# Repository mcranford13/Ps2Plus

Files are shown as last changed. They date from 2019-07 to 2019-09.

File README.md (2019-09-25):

# **PS2 Plus**

This project is a work in progress for making a PS2 Controller emulator. It was designed for the **PIC16F18876** microcontroller. As of right now the controller emulation is working great. There are still some features that I want to add but the main part of the project is complete. 

There are several hold-ups keeping this project from being complete, the main one being that writing an application for the PS2 and being able to send custom commands to the controller is difficult. I am slowly deciphering everything done by the PS2Dev team but it is slow going. If anyone would like to contribute or offer help/advice, I would gladly take it.

This project consists of several smaller projects each with its own folder, and is, as follows:

**firmware** - Main code of the project. Contains the PS2 protocol code.

**hardware** - The schematics and pcb design of the project. Includes information regarding external circuitry.

**updater** - The PS2 application for updating the controller.

**bootloader** - The bootloader code for the mcu.

**docs** - Contains datasheets, pinouts, and other useful documentation.

## **TODO**

- Bootloader
- PS2 Updater Application

## **Build**

You will need a pickit3, MPLAB (_free_), and XC8 compiler to flash this. To build from source, open the firmware project in MPLAB and click 'run'. This will compile the project and then initiate the transfer to the mcu.

The correct pinout of the microcontroller can be found in the **docs** folder.

## **Analog Stick Setup**

> 1. Press Select, L1, and L2 to enter configuration mode. The PS2 should say that there is no controller connected (if you are in a game).
> 2. Move the analog sticks slowly in a circle.
> 3. Press Select, L1, and R1 to exit. The PS2 should now recognize the controller.
> 4. Reboot the controller (rebooting the ps2 works too).
> Analog sticks should now be working.

To set the analog sticks back to the default values:
> 1. Press Select, L1, and L2 to enter configuration mode.
> 2. Press L2, R2, Select, Start.
> 3. Reboot controller (or ps2).

## **Hardware**
Please note that this is my first pcb design and if there are mistakes or any room for improvement please make an issue or a pull request. I am always happy to learn and improve. 

I have recieved feedback that the pad layout of the pcb is not optimal, this occured due to the pins chosen during the prototyping phase and when I switched from the DIP to the TQFP. I intend to update this but I am been really busy with school and life. Therefore I will release it how it is for now, and update it when I get a chance. If anyone would like to submit an updated pcb, I'd be happy to include it. Thanks for your understanding.

## **Acknowledgements**

This project has only moved forward due to these individuals and sites (in no particular order):

1. [Curious Inventor](http://store.curiousinventor.com/guides/PS2) - documentation of the PS2 controller Protocol
2. [Scanlime](https://gist.github.com/scanlime/5042071) - documentation of the PS2 controller protocol
3. [Aurelio Manara](https://github.com/Aurelio92/GCPlus) - for answering countless questions and advice.
4. [Gman](https://gmanmodz.com/) - for initial interest in this project and countless contributions to it.
5. [PS2Dev Team](https://github.com/ps2dev) - for all the hard and amazing work on homebrew for the PS2.

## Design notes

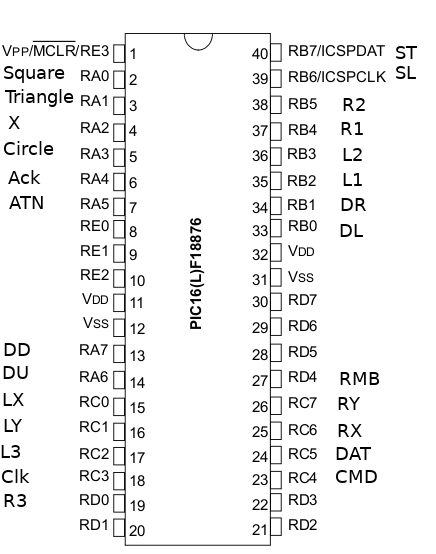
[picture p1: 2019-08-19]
doc/pinout.png

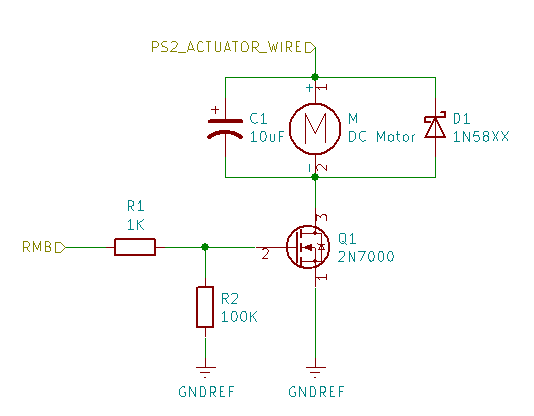
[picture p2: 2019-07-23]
hardware/rumbleSch.png

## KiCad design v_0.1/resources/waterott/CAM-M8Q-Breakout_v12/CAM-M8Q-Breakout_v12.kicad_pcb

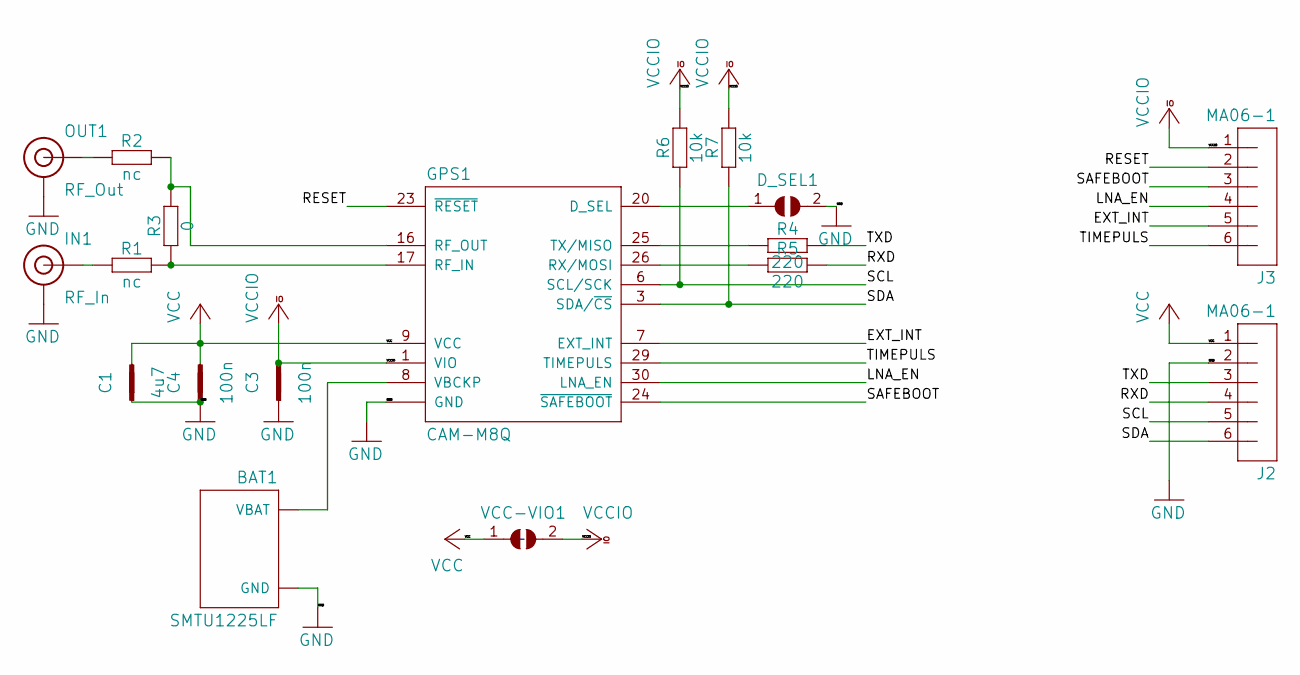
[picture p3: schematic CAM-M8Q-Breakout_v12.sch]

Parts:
BAT1: SMTU1225LF; BAT-SMTU1225LF
C1: 4u7; C0402
C3, C4: 100n; C0402
D_SEL1: JUMPER2-0603-NC; JUMPER2-0603_NC
GPS1: CAM-M8Q
IN1: RF_In; U.FL
J2, J3: MA06-1
OUT1: RF_Out; U.FL
R1, R2: nc; C0402
R3: 0; C0402
R4, R5: 220; C0402
R6, R7: 10k; C0402
VCC-VIO1: JUMPER2-0603-NC; JUMPER2-0603_NC

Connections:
/EXT_INT: GPS1.7 (EXT_INT), J3.5
/LNA_EN: GPS1.30 (LNA_EN), J3.4
/RESET: GPS1.23 (~RESET), J3.2
/RXD: J2.4, R5.2
/SAFEBOOT: GPS1.24 (~SAFEBOOT), J3.3
/SCL: GPS1.6 (SCL/SCK), J2.5, R6.1
/SDA: GPS1.3 (SDA/~CS), J2.6, R7.1
/TIMEPULS: GPS1.29 (TIMEPULS), J3.6
/TXD: J2.3, R4.2
GND: BAT1.- (GND), C1.1, C3.1, C4.1, D_SEL1.2, GPS1.4 (GND), GPS1.5 (GND), GPS1.10 (GND), GPS1.11 (GND), GPS1.12 (GND), GPS1.13 (GND), GPS1.14 (GND), GPS1.15 (GND), GPS1.18 (GND), GPS1.19 (GND), GPS1.21 (GND), GPS1.22 (GND), GPS1.27 (GND), GPS1.31 (GND), IN1.1 (GND), IN1.2 (GND), J2.2, OUT1.1 (GND), OUT1.2 (GND)
unnamed: BAT1.+ (VBAT), GPS1.8 (VBCKP)
unnamed: D_SEL1.1, GPS1.20 (D_SEL)
unnamed: GPS1.16 (RF_OUT), R2.2, R3.2
unnamed: GPS1.17 (RF_IN), R1.2, R3.1
unnamed: GPS1.25 (TX/MISO), R4.1
unnamed: GPS1.26 (RX/MOSI), R5.1
unnamed: IN1.FEED (SIGNAL), R1.1
unnamed: OUT1.FEED (SIGNAL), R2.1
VCC: C1.2, C4.2, GPS1.9 (VCC), J2.1, VCC-VIO1.1
VCCIO: C3.2, GPS1.1 (VIO), J3.1, R6.2, R7.2, VCC-VIO1.2

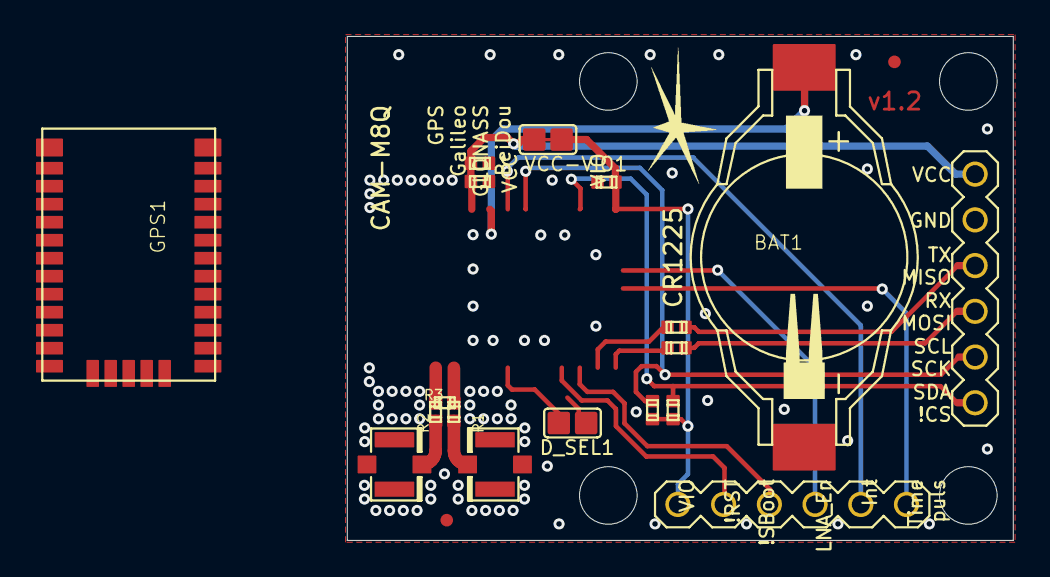
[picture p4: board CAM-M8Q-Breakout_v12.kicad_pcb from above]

Board: 2 copper layers, 37.0 x 28.0 mm, 31 parts (0 on the bottom side), 20 nets.

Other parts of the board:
@HOLE0, @HOLE1, @HOLE2, @HOLE3: (no value)
LOGO1: LOGO-S_PLACE_M; SPARK_TPLACE_M
LOGO2: OSHW_LOGOX0070; OSHW_6X70
LOGO3: LOGO_CE-2; CE_2MM
LOGO4: LOGO_WEEE-4; WEEE_4MM
LOGO5: LOGO_ROHS-2; ROHS_2MM
X1, X2, X3, X4: PASSER-07; PASSER_07MM

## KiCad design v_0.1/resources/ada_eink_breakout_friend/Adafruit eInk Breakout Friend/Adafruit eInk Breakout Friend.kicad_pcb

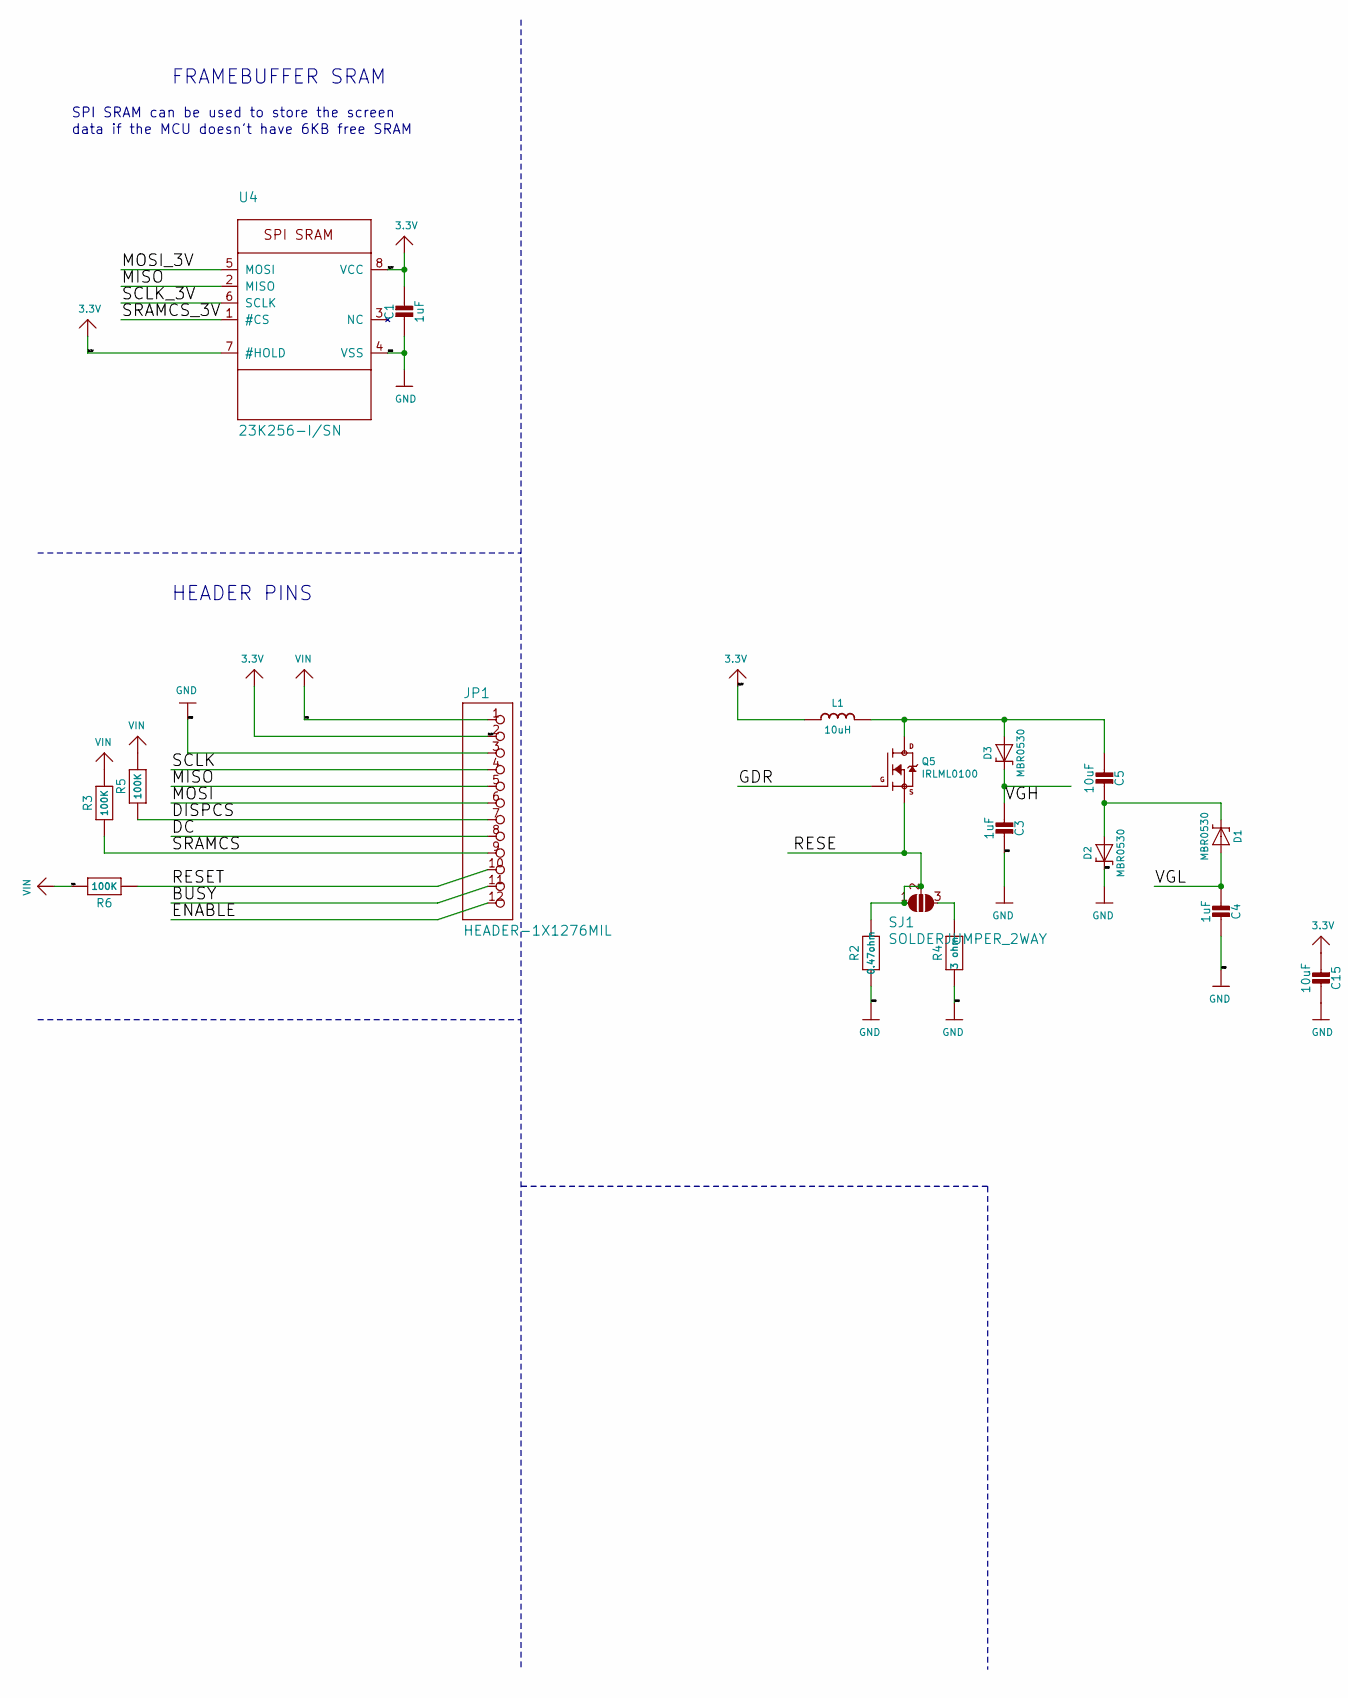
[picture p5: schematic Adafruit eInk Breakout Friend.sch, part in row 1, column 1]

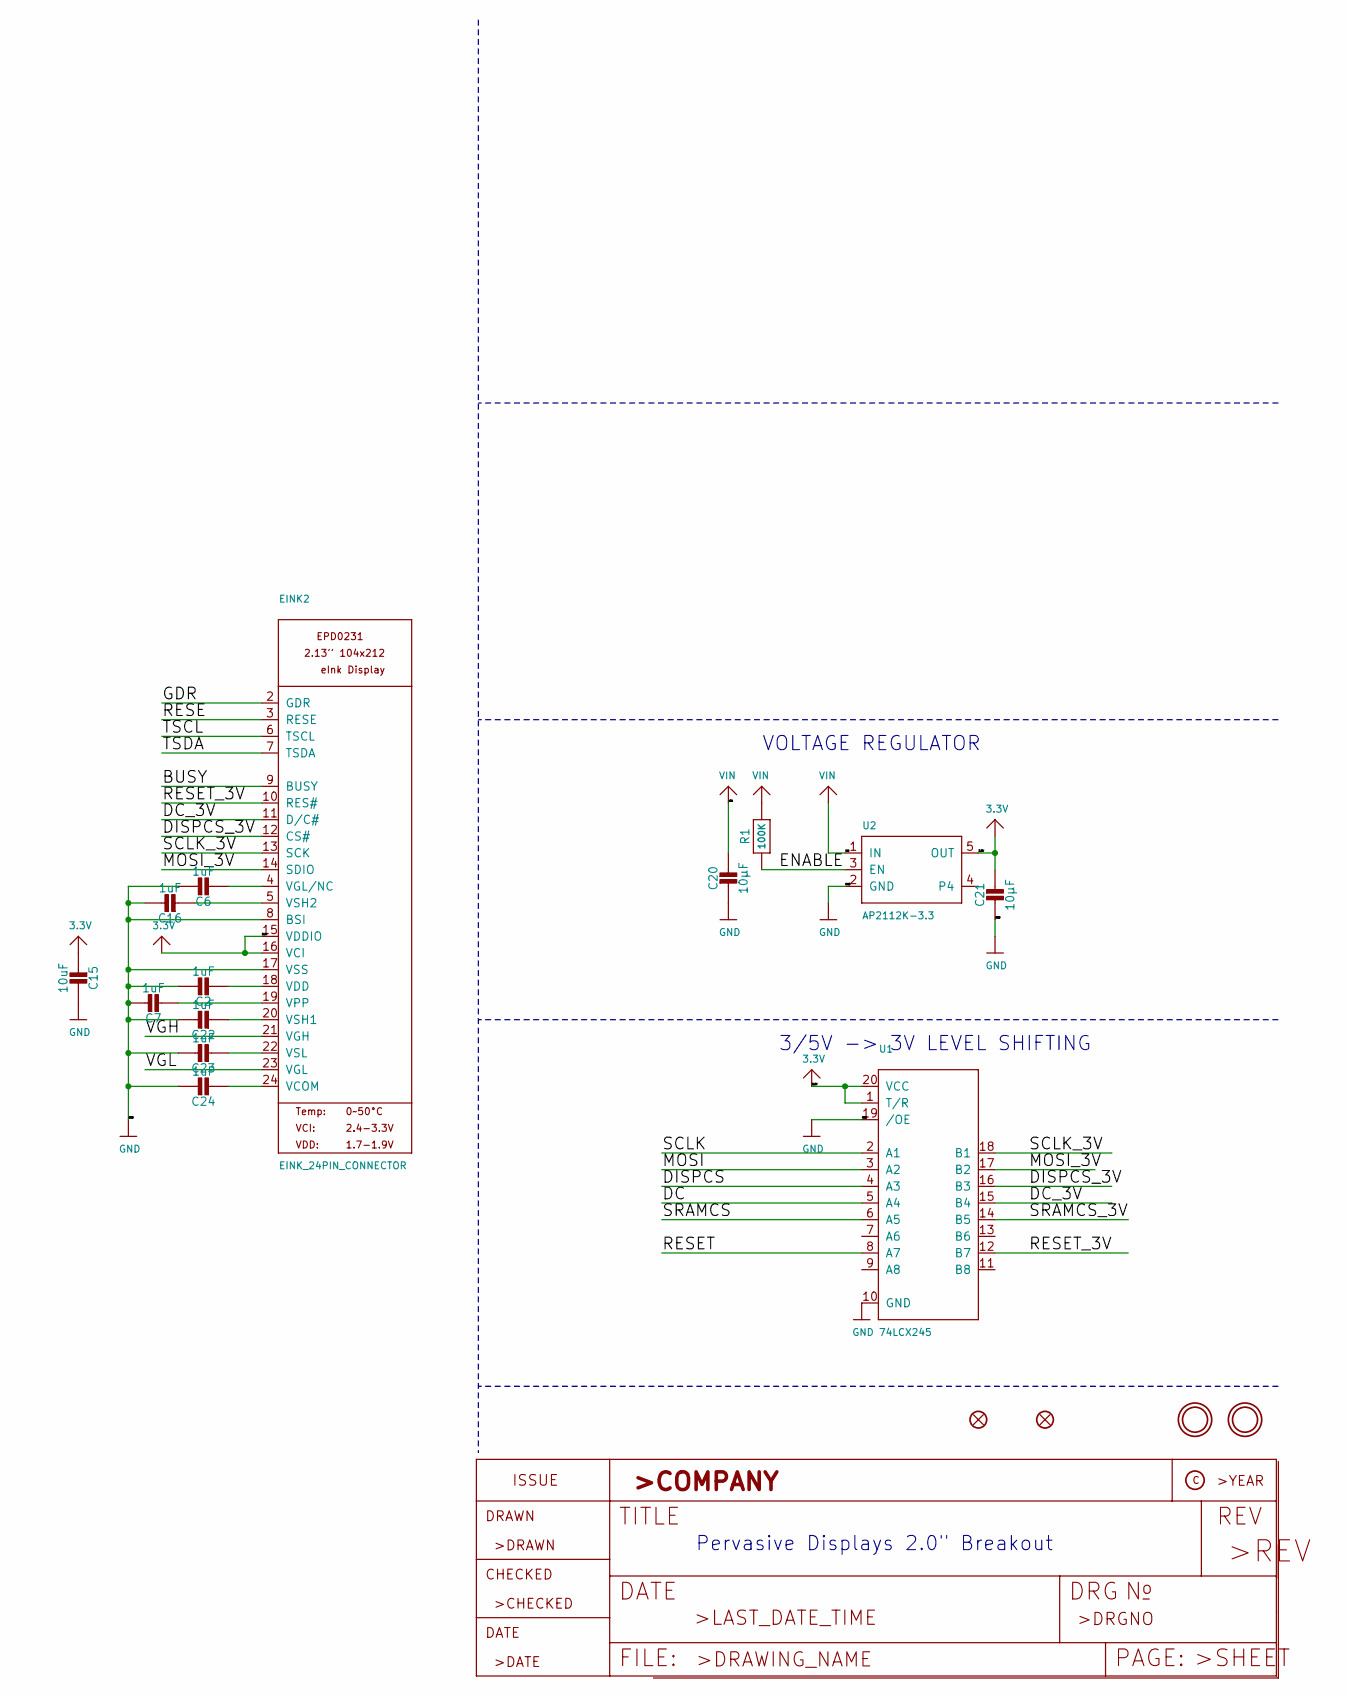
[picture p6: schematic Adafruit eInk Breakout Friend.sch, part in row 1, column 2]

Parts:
C1: 1uF; 0805_10MGAP
C2, C3, C4, C6, C7, C16, C22, C23, C24: 1uF; 0805-NO
C5, C15: 10uF; 0805-NO
C20, C21: 10µF; 0805-NO
D1, D2, D3: MBR0530; SOD-123
EINK2: EINK_24PIN_CONNECTOR; EINK_24PIN
FID2, FID3: FIDUCIAL_1MM
JP1: HEADER-1X1276MIL; 1X12_ROUND_76MIL
L1: 10uH; INDUCTOR_4X4MM_NR401
Q5: IRLML0100; SOT23-3
R1, R3, R5, R6: 100K; 0603-NO
R2: 0.47ohm; 0805-NO
R4: 3 ohm; 0805-NO
SJ1: SOLDERJUMPER_2WAY; SOLDERJUMPER_2WAY_OPEN_NOPASTE
U1: 74LCX245; TSSOP20
U2: AP2112K-3.3; SOT23-5
U4: 23K256-I/SN; SOIC8_150MIL
U$3, U$4: MOUNTINGHOLE2.5; MOUNTINGHOLE_2.5_PLATED

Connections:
3.3V: C1.1, C15.2, C21.1, EINK2.15 (VDDIO), EINK2.16 (VCI), JP1.2, L1.P$2 (2), U1.1 (T/R), U1.20 (VCC), U2.5 (OUT), U4.7 (#HOLD), U4.8 (VCC)
/BUSY: EINK2.9 (BUSY), JP1.11
/DC: JP1.8, U1.5 (A4)
/DC_3V: EINK2.11 (D/C#), U1.15 (B4)
/DISPCS: JP1.7, R5.1, U1.4 (A3)
/DISPCS_3V: EINK2.12 (CS#), U1.16 (B3)
/ENABLE: JP1.12, R1.1, U2.3 (EN)
/GDR: EINK2.2 (GDR), Q5.1 (G)
/MISO: JP1.5, U4.2 (MISO)
/MOSI: JP1.6, U1.3 (A2)
/MOSI_3V: EINK2.14 (SDIO), U1.17 (B2), U4.5 (MOSI)
/RESE: EINK2.3 (RESE), Q5.2 (S), R2.1, SJ1.1, SJ1.2
/RESET: JP1.10, R6.1, U1.8 (A7)
/RESET_3V: EINK2.10 (RES#), U1.12 (B7)
/SCLK: JP1.4, U1.2 (A1)
/SCLK_3V: EINK2.13 (SCK), U1.18 (B1), U4.6 (SCLK)
/SRAMCS: JP1.9, R3.1, U1.6 (A5)
/SRAMCS_3V: U1.14 (B5), U4.1 (#CS)
/TSCL: EINK2.6 (TSCL)
/TSDA: EINK2.7 (TSDA)
/VGH: C3.1, D3.C, EINK2.21 (VGH)
/VGL: C4.1, D1.A, EINK2.23 (VGL)
GND: C1.2, C2.1, C3.2, C4.2, C6.1, C7.1, C15.1, C16.1, C20.2, C21.2, C22.1, C23.1, C24.1, D2.C, EINK2.8 (BSI), EINK2.17 (VSS), JP1.3, R2.2, R4.2, U1.10 (GND), U1.19 (/OE), U2.2 (GND), U4.4 (VSS)
unnamed: C2.2, EINK2.18 (VDD)
unnamed: C5.1, D3.A, L1.P$1 (1), Q5.3 (D)
unnamed: C5.2, D1.C, D2.A
unnamed: C6.2, EINK2.4 (VGL/NC)
unnamed: C7.2, EINK2.19 (VPP)
unnamed: C16.2, EINK2.5 (VSH2)
unnamed: C22.2, EINK2.20 (VSH1)
unnamed: C23.2, EINK2.22 (VSL)
unnamed: C24.2, EINK2.24 (VCOM)
unnamed: R4.1, SJ1.3
VIN: C20.1, JP1.1, R1.2, R3.2, R5.2, R6.2, U2.1 (IN)

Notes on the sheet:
Pervasive Displays 2.0" Breakout
VOLTAGE REGULATOR
3/5V -> 3V LEVEL SHIFTING
HEADER PINS
FRAMEBUFFER SRAM
SPI SRAM can be used to store the screen
data if the MCU doesn't have 6KB free SRAM

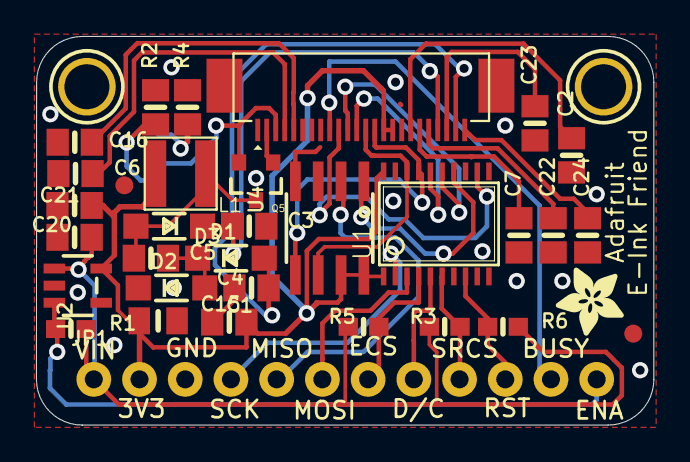
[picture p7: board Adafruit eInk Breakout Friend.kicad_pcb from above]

Board: 2 copper layers, 34.3 x 21.6 mm, 37 parts (0 on the bottom side), 32 nets.

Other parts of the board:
U$2: ADAFRUIT_3.5MM
U$9: PCBFEAT-REV-040

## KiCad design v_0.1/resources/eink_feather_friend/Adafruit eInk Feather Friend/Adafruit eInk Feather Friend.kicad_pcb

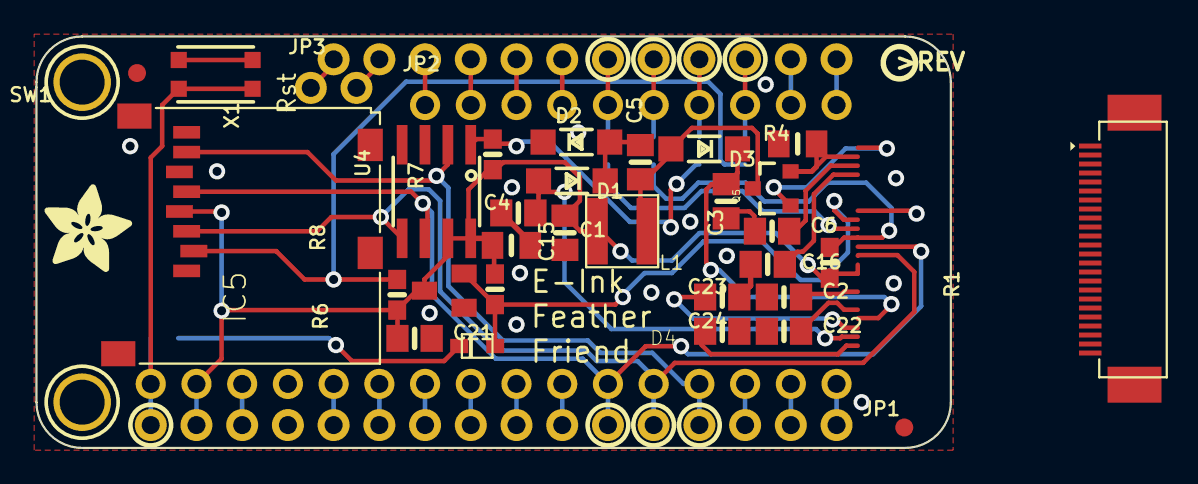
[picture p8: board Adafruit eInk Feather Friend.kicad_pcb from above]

Board: 2 copper layers, 50.8 x 22.9 mm, 47 parts (0 on the bottom side), 47 nets.

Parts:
BUSY1: TPTP15SQ; TP15SQ
C1: 1uF; 0805_10MGAP
C2, C6: 1uF/10V; 0805-NO
C3, C4, C22, C23: 1uF/25V; 0805-NO
C5: 10uF/25V; 0805-NO
C15: 10uF/10V+; 0805-NO
C16, C24: 1uF; 0805-NO
C21: 10µF; 0805-NO
D1, D2, D3: MBR0530; SOD-123
D4: 1N4148; SOD-323F
EINK1: EINK_24PIN_CONNECTOR; EINK_24PIN
FID1, FID3: FIDUCIAL_1MM
IC5: AXP803; SOT23
JP1: HEADER-1X16ROUND; 1X16_ROUND
JP2: HEADER-1X10ROUND; 1X10_ROUND
JP3: HEADER-1X2ROUND; 1X02_ROUND
L1: 10uH; INDUCTOR_4X4MM_NR401
MS1: FEATHERWING_NOHOLES
Q5: IRLML0100; SOT23-3
R1, R6, R7, R8: 100K; 0603-NO
R4: .47ohm; 0805_10MGAP
SJ1, SJ2, SJ3, SJ4, SJ5: SOLDERJUMPER_CLOSED; SOLDERJUMPER_CLOSEDWIRE
SW1: 6mm SMT; BTN_KMR2_4.6X2.8
U4: 23K256-I/SN; SOIC8_150MIL
U$3, U$4: MOUNTINGHOLE2.5; MOUNTINGHOLE_2.5_PLATED
U$5: THINKINK_1.25IN
U$6: FEATHERLOGO_MED
U$8: ADAFRUIT_5MM
U$9: PCBFEAT-REV-040
U$17: ADAFRUIT_3.5MM
X1: MICROSD

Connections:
3.3V: C1.1, C15.2, C21.1, EINK1.15, EINK1.16, IC5.3, JP1.15, L1.P$2, MS1.2, R1.2, R6.2, R7.2, R8.2, U4.7, U4.8, X1.4
/BUSY: BUSY1.TP, EINK1.9
/DC: EINK1.11, SJ4.2
/EINK_CS: EINK1.12, R1.1, SJ1.2
/EINK_RESET: D4.A, EINK1.10, IC5.2, R8.1
/GDR: EINK1.2, Q5.1
/MISO: JP1.4, MS1.13, U4.2, X1.7
/MOSI: EINK1.14, JP1.5, MS1.12, U4.5, X1.3
/RESE: EINK1.3, Q5.2, R4.1
/RESET: JP1.16, MS1.1, SJ5.2, SW1.B, SW1.B'
/SCLK: EINK1.13, JP1.6, MS1.11, U4.6, X1.5
/SD_CS: R6.1, SJ3.2, X1.2
/SRAM_CS: R7.1, SJ2.2, U4.1
/VGH: C3.1, D3.C, EINK1.21
/VGL: C4.1, D1.A, EINK1.23
GND: C1.2, C2.1, C3.2, C4.2, C6.1, C15.1, C16.1, C21.2, C22.1, C23.1, C24.1, D2.C, EINK1.8, EINK1.17, IC5.1, JP1.13, MS1.4, R4.2, SW1.A, SW1.A', U4.4, X1.6, X1.MT1, X1.MT2
unnamed: C2.2, EINK1.18
unnamed: C5.1, D3.A, L1.P$1, Q5.3
unnamed: C5.2, D1.C, D2.A
unnamed: C6.2, EINK1.4
unnamed: C16.2, EINK1.5
unnamed: C22.2, EINK1.20
unnamed: C23.2, EINK1.22
unnamed: C24.2, EINK1.24
unnamed: D4.C, SJ5.1
unnamed: JP1.1, MS1.16
unnamed: JP1.2, MS1.15
unnamed: JP1.3, MS1.14
unnamed: JP1.7, MS1.10
unnamed: JP1.8, MS1.9
unnamed: JP1.9, MS1.8
unnamed: JP1.10, MS1.7
unnamed: JP1.11, MS1.6
unnamed: JP1.12, MS1.5
unnamed: JP1.14, MS1.3
unnamed: JP2.1, MS1.26
unnamed: JP2.2, MS1.25
unnamed: JP2.3, MS1.24
unnamed: JP2.4, MS1.23
unnamed: JP2.5, MS1.22, SJ4.1
unnamed: JP2.6, MS1.21, SJ1.1
unnamed: JP2.7, MS1.20, SJ2.1
unnamed: JP2.8, MS1.19, SJ3.1
unnamed: JP2.9, MS1.18
unnamed: JP2.10, MS1.17
unnamed: JP3.1, MS1.28
unnamed: JP3.2, MS1.27

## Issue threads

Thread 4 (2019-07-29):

PCB

mcranford13, 2019-07-29:
I'm currently designing a pcb that can be ordered and then populated with this mcu. Should be ready to go in a few days. Will be pushed to the hardware section.

Gameboypi, 2019-08-01:
will do you think the PIC16(L)F18856/76 40-pin UQFN (5x5) will work insted of the big one?
if it's I designed a pcb for it.
let me know if it's gonna work i will send you the files
thanks for sharing this!!
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

mcranford13, 2019-08-01:
Almost done with this. Just need to make it a little bit more streamlined for portables. Should be released later today.

mcranford13, 2019-08-26:
PCB Design is complete although not optimal.

Closed 2019-08-26.

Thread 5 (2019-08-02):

Feature Request: Trigger the PS2 reset, when powered on

Nold360, 2019-08-02:
**Problem:** When building a PS2 portable, you have to short the "reset"-pad to ground, to actually power on the PS2.

**Possible solution:** Connect a pin of the PIC to the Reset-pad & short it to gnd for a few milliseconds. The impulse should be triggered with a little delay after powering on the PIC.

Also there could be a key combination to hard-reset the PS2.

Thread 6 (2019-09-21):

Nintendo switch joystick

Gameboypi, 2019-09-21:
Hi
Thanks for sharing this awesome project!
I have a question about nintendo switch joysticks
Is it possible to use them with the ps2plus?
I tried it but it seems to be not very compatible with ps2plus even if I setup them by “select + L1 + L2” still not getting them working properly

Any tips

Closed 2019-09-22.

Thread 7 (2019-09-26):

Games not compatible with Ps2Plus

Gameboypi, 2019-09-26:
Hi
I just found some games/apps are not compatible with Ps2Plus

- Lara Croft tomb raider anniversary
- Lara Croft tomb raider legends
- Lara Croft tomb raider underworld
- Yakuza
- Crash Twinsanity
- GSM “App not game”

I will update the list if I find other games not working

Thank you!

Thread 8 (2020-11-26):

I can't Open the Shematic file in Eagle or other

millomaker, 2020-11-26:
I can't Open the Shematic file in Eagle or other, I have tested many times but impossible to open, he give me an error :

A starting tag is expected.
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

millomaker, 2020-11-27:
Benge you are idiot ! It work with KiCad !

Closed 2020-11-27.

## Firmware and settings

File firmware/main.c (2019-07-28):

/*
 * File:   main.c
 * Author: Matthew Cranford
 *
 * Created on June 25, 2019, 10:49 PM
 */


#include <xc.h>
#include "Opcodes.h"
#include "Spi.h"
#include "PicConfig.h"
#include "Controller.h"
#include "Nvm.h"

char response[20] = {ANALOG_MODE, END_HEADER};
char responseLength = 9;
char cmdCounter = 0;
char analogMode = 1; //0 for digital mode
char escapeMode = 0;
char previousCmd;


void pollController(char response[20]) {

    responseLength = 5;

    response[2] = digitalStateFirst;
    response[3] = digitalStateSecond;

    response[4] = rxData;
    response[5] = ryData;
    response[6] = lxData;
    response[7] = lyData;

    if (analogMode) {

        responseLength = 20;

        response[8] = analogStateFirst[2];
        response[9] = analogStateFirst[0];
        response[10] = analogStateFirst[3];
        response[11] = analogStateFirst[1];
        response[12] = analogStateSecond[3];
        response[13] = analogStateSecond[2];
        response[14] = analogStateSecond[1];
        response[15] = analogStateSecond[0];
        response[16] = analogStateSecond[5];
        response[17] = analogStateSecond[4];
        response[18] = analogStateSecond[7];
        response[19] = analogStateSecond[6];
    }


}

void __interrupt() PS2Command() {

    if (SSP1IF) {

        char cmd = spiRead();

        switch (cmdCounter) { //We only care about the first command, the 3rd command and the 4th.

            case 3:

                switch (previousCmd) {
                    
                    case MAIN_POLLING:
                       
                        if(cmd == 0x80)
                            SMALL_MOTOR = 1;
                        else
                            SMALL_MOTOR = 0;
                        
                        break;
                    case ENTER_EXIT_ESCAPE:

                        if (cmd == 0x80)
                            escapeMode = 1;
                        else
                            escapeMode = 0;

                        break;
                    case ANALOG_DIGITAL_SWITCH:

                        if (cmd == 0x80)
                            analogMode = 1;
                        else
                            analogMode = 0;
                        break;

                    case DEVICE_DESCRIPTOR_LAST:

                        if (cmd == 0x80) {
                            response[2] = 0x00;
                            response[3] = 0x00;
                            response[4] = 0x00;
                            response[5] = 0x60;
                            response[6] = 0x00;
                            response[7] = 0x00;
                        } else {
                            response[2] = 0x00;
                            response[3] = 0x00;
                            response[4] = 0x00;
                            response[5] = 0x20;
                            response[6] = 0x00;
                            response[7] = 0x00;
                        }

                        break;


                    case CONTROL_RESPONSE:
                        //Obtain which buttons we want to collect analog data from here
                        break;

                }

                break;



            case 4:

                switch (previousCmd) { //Large Motor

                    case MAIN_POLLING:
                        if (cmd != 0xFF) {
                           // LARGE_MOTOR = 1;
                            //send pwn signal to motor i.e. signalPin = cmd;
                        } else {
                            //LARGE_MOTOR = 0;
                            //signalPin = 0x00
                        }
                        break;
                    case CONTROL_RESPONSE:
                        //Obtain which buttons we want to collect analog data from here
                        break;

                }

                break;

            default:

                switch (cmd) {

                    case INIT_PRESSURE_SENSOR:
                        /* 
                         * This command tells us what buttons it wants 
                         * from analog information from.
                         */

                        if (analogMode) {
                            response[2] = 0xFF;
                            response[3] = 0xFF;
                            response[4] = 0xC0; //0x03 reversed
                            response[5] = 0x00;
                            response[6] = 0x00;
                            response[7] = 0x5A;
                        } else {
                            response[2] = 0x00;
                            response[3] = 0x00;
                            response[4] = 0x00;
                            response[5] = 0x00;
                            response[6] = 0x00;
                            response[7] = 0x5A;
                        }

                        break;

                    case BUTTON_INCLUSION:
                        /*
                         * This command asks for which buttons and sticks are turned on. This feature
                         * is controlled by CONTROL_RESPONSE. The response is 9 bytes long with 18 total bits
                         * that represent the different button and analog stick states.
                         */
                        if (analogMode) {
                            response[2] = 0xFF;
                            response[3] = 0xFF;
                            response[4] = 0xC0; //0x03 Reversed 
                            response[5] = 0x00;
                            response[6] = 0x00;
                            response[7] = 0x5A;
                        } else {
                            response[2] = 0x00;
                            response[3] = 0x00;
                            response[4] = 0x00;
                            response[5] = 0x00;
                            response[6] = 0x00;
                            response[7] = 0x5A;
                        }


                        break;

                    case MAIN_POLLING:
                        /*
                         * This is the main polling command. If the 3rd and 4th cmd bytes
                         * of the command have data in them then we need to turn on motors.
                         */

                        pollController(response);
                        previousCmd = cmd;


                        break;

                    case ENTER_EXIT_ESCAPE:
                        /*
                         * This command acts exactly like MAIN_POLLING command 
                         * except that depending on the 3rd byte tells the controller
                         * to be in escape mode or not.
                         */
                        pollController(response);
                        previousCmd = cmd;
                        break;

                    case ANALOG_DIGITAL_SWITCH:
                        /*
                         * Depending on what the 3rd byte of this command is
                         * the controller will change between analog and digital states.
                         */

                        response[2] = 0x00;
                        response[3] = 0x00;
                        response[4] = 0x00;
                        response[5] = 0x00;
                        response[6] = 0x00;
                        response[7] = 0x00;


                        previousCmd = cmd;
                        break;

                    case STATUS_INFO:
                        /*
                         * The PS2 is requesting certain information about the controller
                         * like whether the controller is a guitar hero controller
                         * or DualShock controller.
                         * 
                         */

                        response[2] = 0xC0; //0x03 reversed (DualShock)
                        response[3] = 0x40; //0x02 reversed

                        if (analogMode)
                            response[4] = 0x80; //States whether the LED is on.
                        else
                            response[4] = 0x00;

                        response[5] = 0x40; //0x02 reversed
                        response[6] = 0x80; //0x01 reversed
                        response[7] = 0x00;


                        break;

                    case DEVICE_DESCRIPTOR_FIRST:
                        /*
                         * This commands deal with reading a fixed constant from
                         * the controller. The following was obtained from a sample
                         * playing Kingdom Hearts 2. The one I found online did not work.
                         */
                        response[2] = 0x00;
                        response[3] = 0x00;
                        response[4] = 0x80; //0x01 reversed
                        response[5] = 0x80;
                        response[6] = 0x80;
                        response[7] = 0x50; //0x0A reversed

                        break;

                    case DEVICE_DESCRIPTOR_SECOND:
                        /*
                         * This commands deal with reading a fixed constant from
                         * the controller. The following was obtained from a sample
                         * playing Kingdom Hearts 2. The one I found online did not work
                         */

                        response[2] = 0x00;
                        response[3] = 0x00;
                        response[4] = 0x40; //0x02 reversed
                        response[5] = 0x00;
                        response[6] = 0x80; //0x01 reversed
                        response[7] = 0x00;


                        break;

                    case DEVICE_DESCRIPTOR_LAST:
                        /*
                         * This commands deal with reading a fixed constant from
                         * the controller. The following was obtained from a sample
                         * playing Kingdom Hearts 2. The one I found online did not work
                         */

                        response[2] = 0x00;
                        response[3] = 0x00;
                        response[4] = 0x00;
                        response[5] = 0x20; //04 reversed
                        response[6] = 0x00; //0x01 reversed
                        response[7] = 0x00;

                        previousCmd = cmd;

                        break;

                    case MAP_MOTOR:
                        /*
                         * This command tells the controller that MAIN_POLLING will now issue commands
                         * to control the motors. There is no need to keep track of the state since we 
                         * have logic in place to already handle this scenario. Instead we just send
                         * a default response.
                         */

                        response[2] = 0x00;
                        response[3] = 0x01;
                        response[4] = 0xFF;
                        response[5] = 0xFF;
                        response[6] = 0xFF;
                        response[7] = 0xFF;

                        break;

                    case CONTROL_RESPONSE:
                        /*
                         * Difficult command as it controls whether or not we return analog values for buttons
                         * i.e. keeping track of more state. For now will create default response. 
                         * Further testing across many different games is needed to see 
                         * if this will cause problems
                         */

                        response[2] = 0x00;
                        response[3] = 0x00;
                        response[4] = 0x00;
                        response[5] = 0x00;
                        response[6] = 0x00;
                        response[7] = 0x5A;

                        break;

                }

                break;
        }

        //Output the correct controller state
        if (escapeMode) {
            response[0] = ESCAPE_MODE;
        } else {

            if (analogMode)
                response[0] = ANALOG_MODE;
            else
                response[0] = DIGITAL_MODE;

        }


        //transmit
        spiWrite(response[cmdCounter]);

        //Increment index to next command
        if (cmdCounter < responseLength) {
            cmdCounter++;
        }


        ACK = 0;
        __delay_us(1);
        ACK = 1;
     
        SSP1IF = 0;

    }


}



void main(void) {

    picInit();
    adcInit();
    lutInit();

    response[1] = END_HEADER; //Finish header

    char slaveSelect;
    char slaveSelectStatePrev = 0;
    char count = 0;
    ACK = 1; //Acknowledge is an active low line, so we initialize it high.
   
    
    while (1) {

        
        //L1 L2 Select
        if(digitalStateFirst == 0x7F && digitalStateSecond == 0x5F){ 
            
            configureController();

        }
        
        
        slaveSelect = SLAVE_SELECT;

        if (slaveSelect) {
            count++;
        }

        if (slaveSelect ^ slaveSelectStatePrev) {
            count = 0;
        }

        slaveSelectStatePrev = slaveSelect;

        if (count >= 3) { //Clear transmission counters

            cmdCounter = 0;
            responseLength = 9;
            SSP1BUF = 0xFF;
            previousCmd = 0x00;
        }


        readController(analogMode);
        
        readControllerAnalog();
    }
    

    
}

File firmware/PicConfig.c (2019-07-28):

/*
 * File:   PicConfig.C
 * Author: Matthew Cranford 
 */


#include "PicConfig.h"

void ppsUnlock() {
    PPSLOCK = 0x55;
    PPSLOCK = 0xAA;
    PPSLOCK = 0; //PPS unlocked	
}

void ppsLock() {
    PPSLOCK = 0x55;
    PPSLOCK = 0xAA;
    PPSLOCK = 1; //PPS locked   	
}

void adcInit() {
    ADCON0 = 0x04;
    ADCON1 = 0;
    ADCON2 = 0;
    ADREF = 0; //VDD is VREF    
    ADCLK = 0x3F; //ADC clock = FOSC/128
    ADCON0bits.ADON = 1;
}



void picInit() {

    //all ports inputs
    TRISA = 0xFF;
    TRISB = 0xFF;
    TRISC = 0xFF;
    TRISD = 0xEF; //Rumble on RD4
    TRISE = 0xFF;

    //analog pins on RC0, RC1, RC6, RC7  
    ANSELA = 0;
    ANSELB = 0;
    ANSELC = 0xC3;
    ANSELD = 0;
    ANSELE = 0;

    //weak pull-ups on digital button pins
    WPUA = 0xCF;
    WPUB = 0xFF;
    WPUC = 0x04;
    WPUD = 0x01;
    WPUE = 0;

    //enable SPI slave mode
    spiInit(SPI_SLAVE_SS_EN, SPI_DATA_SAMPLE_MIDDLE, SPI_CLOCK_IDLE_HIGH, SPI_ACTIVE_2_IDLE);

    TRISCbits.TRISC5 = 0; //clear pin for SDO1
    TRISAbits.TRISA4 = 0; //Set RA4 as output for ack
    ppsUnlock();

    RC5PPS = 0x15; //SDO1 on RC5 

    ppsLock();

    //enable interrupts
    INTCONbits.GIE = 1; //enable all global interrupts
    INTCONbits.PEIE = 1; //peripheral interrupt enable    
    SSP1IF = 0;
    SSP1IE = 1; //enable MSSP interrupt    
}

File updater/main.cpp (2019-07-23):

/*
 * updateController.cpp
 * 
 * Copyright 2019 Matthew <Matthew@HOENHEIM>
 * 
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
 * 
 */
 

#include <stdio.h>
#include <stdlib.h>
#include <fstream>
#include <iostream>

#include <tamtypes.h>
#include <sifrpc.h>
#include <debug.h>
#include <fileXio_rpc.h>
#include <loadfile.h>
#include <timer.h>





using namespace std;


void delay(void){
	
	
	for(int i = 0; i < 100; i++){
		
		for(int j = 0; i < 1000; j++){
		}
	}
	
}




void printTitle(void){
	
	init_scr();
	scr_printf("====================\n");
	scr_printf("\tPS2+ Updater\t\n");
	scr_printf("====================\n");
	
	
}

void loadModules(){
	
	scr_printf("Loading modules....\n");
	
	//FileIO
	SifLoadModule("rom0:iomanX.irx", 0, NULL);
	SifLoadModule("rom0:fileXio.irx", 0, NULL);
	SifLoadModule("rom0:SIO2MAN", 0, NULL);

	//USB
	SifLoadModule("rom0:usbd", 0, NULL);
	SifLoadModule("rom0:usbmass_fd", 0, NULL);
	
	//Controller
	SifLoadModule("rom0:sio2Cmds", 0, NULL);
	
	
	SifInitRpc(0);
	scr_printf("All modules loaded!\n");
	
}





int main(int argc, char *argv[]){
	
	
	
	printTitle();
	
	loadModules();
	
	fileXioInit();
	
	scr_printf("Checking for update.bin on root of usb drive...");
	ifstream file;
	
	file.open("mass:update.bin");
	
	if(file != NULL) { scr_printf("File found!\n");}
	else{scr_printf("File not found! Quitting..."); return -1;}
	
	
	
	fileXioExit();
	
	
	delay();
	
		return 0;
	
}

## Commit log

2019-07-23 public release
    [ps2plus.kicad_pcb, ps2plus.sch, rumble.sch]
2019-07-31 pcb design complete
    [ps2plus-B_Cu.gbr, ps2plus-B_Mask.gbr, ps2plus-B_SilkS.gbr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]
2019-08-19 Updated pcb design, still not completely optimal
    [ps2plus-B_Cu.gbr, ps2plus-B_Mask.gbr, ps2plus-B_SilkS.gbr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]
2019-08-19 Updated pinout schematic

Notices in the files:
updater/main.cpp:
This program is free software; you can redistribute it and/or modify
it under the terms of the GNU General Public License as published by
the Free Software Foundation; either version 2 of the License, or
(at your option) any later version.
